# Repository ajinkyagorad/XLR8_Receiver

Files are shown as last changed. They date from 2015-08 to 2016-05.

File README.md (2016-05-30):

# XLR8_Receiver
XLR8 Receiver (IIT Bombay) design files

###For more info go to [Document](https://github.com/ajinkyagorad/XLR8_Receiver/tree/master/Document)
###The android mobile app is available [here](https://play.google.com/store/apps/details?id=com.udiboy.xlr8remotecontrol)

##Circuit Schematic
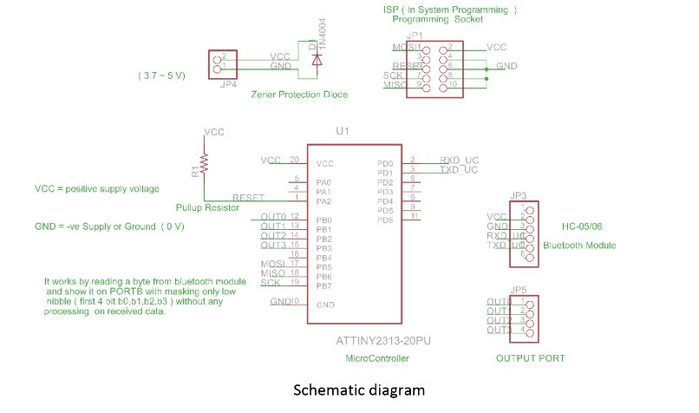
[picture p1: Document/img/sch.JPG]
Circuit Schematic

##Circuit PCB
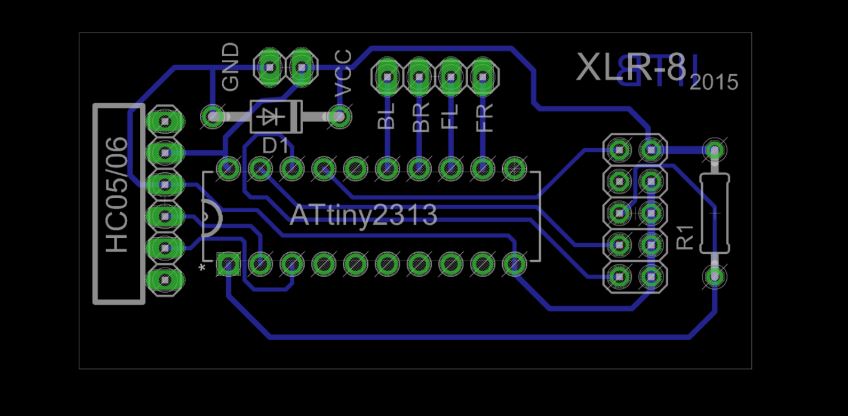
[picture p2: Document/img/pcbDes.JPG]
Circuit PCB

##Flowchart of Implementation (on uC)
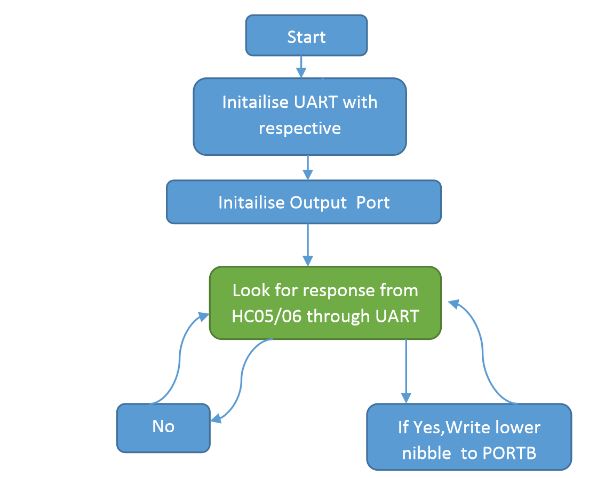
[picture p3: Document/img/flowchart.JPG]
flowchart


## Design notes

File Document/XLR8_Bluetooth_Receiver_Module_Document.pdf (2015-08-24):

XLR8 Bluetooth Receiver ModuleDocument

Electronics Club

IIT Bombay

This page is intentionally left blank

## About

This document describes the implementation of Bluetooth controlled port using Attiny2313A.

This document ( program ) is limited to 4 bit output , but can be easily changed upto 8 bits & beyond by configuring the data packet protocol ( user decided ).

## Index

## Contents

## Introduction

Bluetooth controlled port is the digital output access over Bluetooth ( in this case 4 bit access) and is achieved using a Bluetooth module (HC05/06) and a microcontroller ( ATtiny2313A).

This can be controlled through any Bluetooth device which can access the connection to the HC05/06.

## Software

Following software is used in making of the program & programming

- Atmel Studio 6.0 - alternative is WinAVR (windows), AVRgcc (Linux)
- Avrdude – alternative is Extreme Burner (GUI)
- EAGLE 7.0 (for CAD designing ) – alternative (free source : KiCAD )

## Hardware

Following hardware is used

- HC05/06 Bluetooth Module
- Attiny 2313A microcontroller
- USBASP programmer

## Schematic & PCB Diagram

Schematic & PCB designing is done in EAGLE7.2.0 Light Version

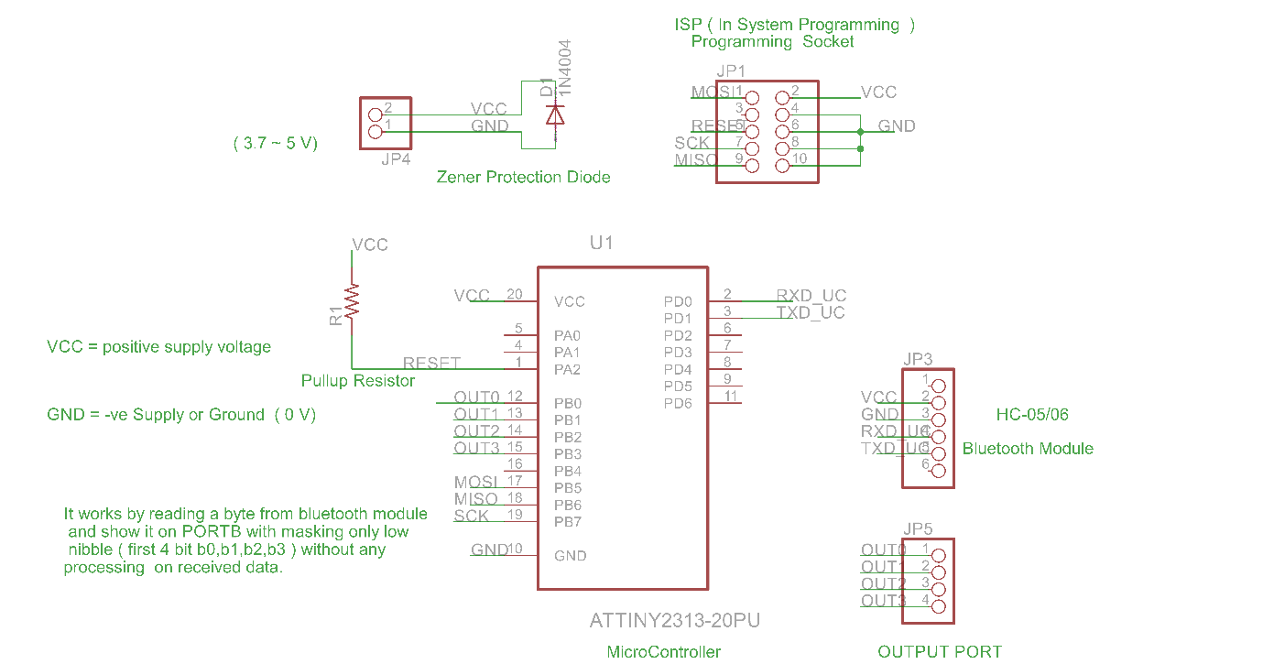
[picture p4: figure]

Schematic diagram

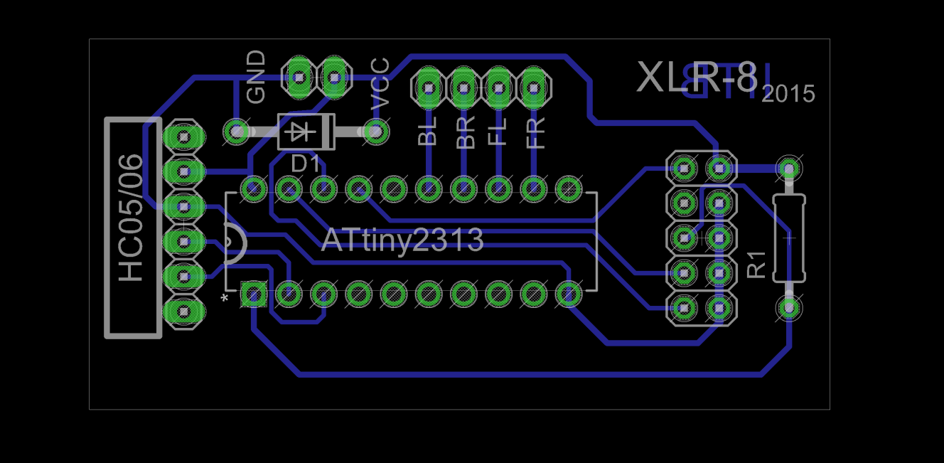
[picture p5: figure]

PCB top-bottom-silkscreen

Eagle files can be found at https://github.com/ajinkyagorad/XLR8_Receiver/tree/master/EAGLE_Files

## Software

Software ( program ) for ATtiny2313 is written in Atmel Studio 6.0

/*
* XLR8_module.c
*
* Created: 20-07-2015 10:07:35 PM
* Author: Ajinkya & Meet
*/
#include <avr/io.h> | // definations for registers

//default frequency of operation 1M
void USARTInit(unsigned int ubrr_value, uint8_t x2, uint8_t stopbits) { //from datasheet :
// Set baud rate
UBRRL = ubrr_value & 255;
UBRRH = ubrr_value >> 8;
// Frame Format: asynchronous, 8 data bits, no parity, 1/2 stop bits
UCSRC = _BV(UCSZ1) | _BV(UCSZ0);
if(stopbits == 2) UCSRC |= _BV(USBS);
if(x2) UCSRA = _BV(U2X); // 2x
// USART Data Register Empty Interrupt Enable UCSRB = _BV(UDRIE);
// Enable The receiver and transmitter
UCSRB |= _BV(RXEN) | _BV(TXEN);
}

int main() {

USARTInit(5, 0, 1); // initialise uart to baud rate 9600, no parity , 1 stopbit
DDRB=0xFF; | // make all pins on port B as output
PORTB = 0x00; | // initially make all pins low
while(1) | //endless loop
while( !(UCSRA & (1<<RXC)) ); | // wait for data to be received in
uart UDR register
char temp = UDR; | // copy data,
PORTB = UDR&(0X0F); | // write data directly
to port
}
}

For more information related to microcontroller refer http://www.atmel.com/images/doc2543.pdf

### Program Flowchart

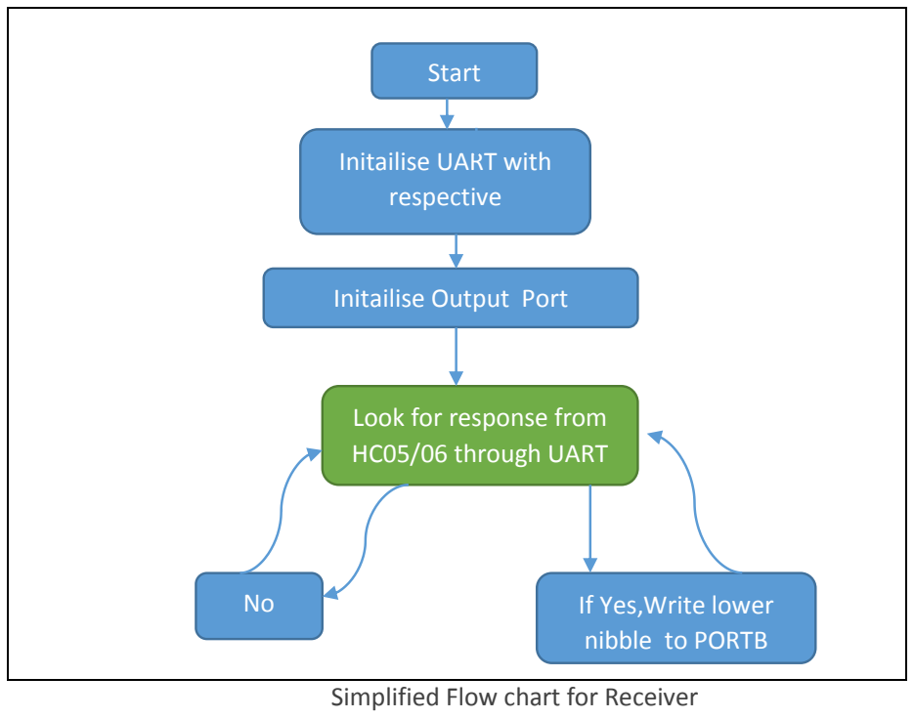
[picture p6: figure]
Simplified Flow chart for Receiver; Start; Initailise UART with respective; Initailise Output Port; Look for response from HC05/06 through UART; If Yes,Write lower nibble to PORTB

This program directly writes the data received through Bluetooth Module ( 1 byte ) to PORTB of the ATtiny 2313A.

The schematic diagram ( circuit diagram ) given is for low nibble ( 4 lower bits) of PORTB.

The default clock frequency of 1MHz (internal RC oscillator) is used as a clock source.

## Programming

Avrdude programming command using usbasp is

avrdude –c usbasp –p attiny2313 –U flash:w:XLR8_module.hex
For more details refer ‘XLR8_Bluetooth_Programming_Guide.pdf’ at https://github.com/ajinkyagorad/XLR8_Receiver/tree/master/Document

## PCB Soldering Tutorial

Refer ‘XLR8_Bluetooth_RF_module_Soldering_guide.pdf’ for picture guide at https://github.com/ajinkyagorad/XLR8_Receiver/tree/master/Document

## Future Work

- This can be improved for larger number of bit access by defining a Bluetooth UART packet protocol, or up to n bits by masking for first n bits ( n < 8 ) according to application.
- If possible to change the firmware on the BC417 chip on Bluetooth module for directly using HC05 pins remotely without the need for the external microcontroller (see http://byron76.blogspot.in/ ). Which can enable many functions like sampling voltage remotely without uC and at a low cost.

## Reference Links

- Github Project Link https://github.com/ajinkyagorad/XLR8_Receiver
- Eagle files https://github.com/ajinkyagorad/XLR8_Receiver/tree/master/EAGLE_Files
- Datasheet for ATtiny2313A http://www.atmel.com/images/doc2543.pdf
- Guides documents
https://github.com/ajinkyagorad/XLR8_Receiver/tree/master/Document
- Interesting future work http://byron76.blogspot.in/
- Eagle Download http://www.cadsoftusa.com/download-eagle/
- Extreme Burner http://extremeelectronics.co.in/avr-tutorials/gui-software-for-usbasp-based-usb-avr-programmers/ (http://extremeelectronics.co.in/avr-tutorials/gui-software-for-usbasp-based-usb-avr-programmers/)
- KiCAD http://www.kicad-pcb.org/display/KICAD/KiCad+EDA+Software+Suite
- Atmel Studio http://www.atmel.com/microsite/atmel_studio6/
- WinAVR http://winavr.sourceforge.net/

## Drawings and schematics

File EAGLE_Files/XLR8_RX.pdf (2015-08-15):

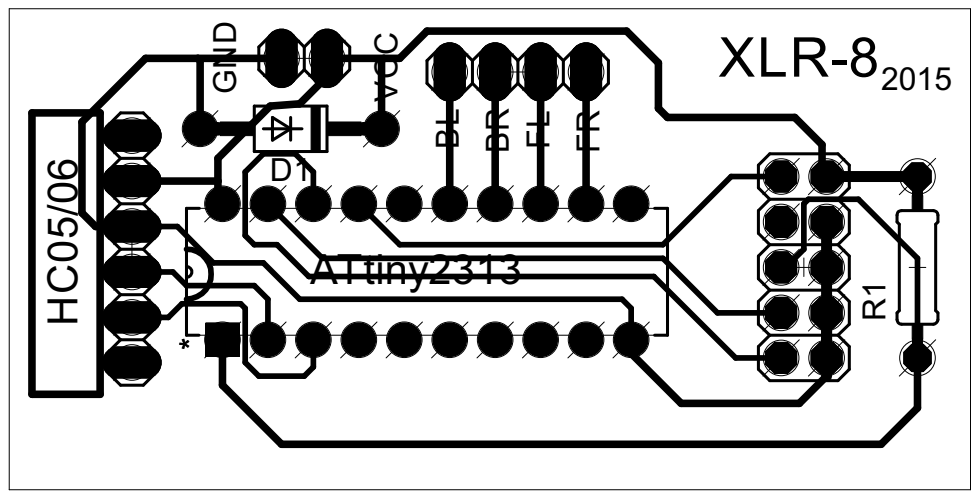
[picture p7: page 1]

VCC GND FRFL BRBL ATtiny2313 HC05/06 XLR-82015 * R1 D1

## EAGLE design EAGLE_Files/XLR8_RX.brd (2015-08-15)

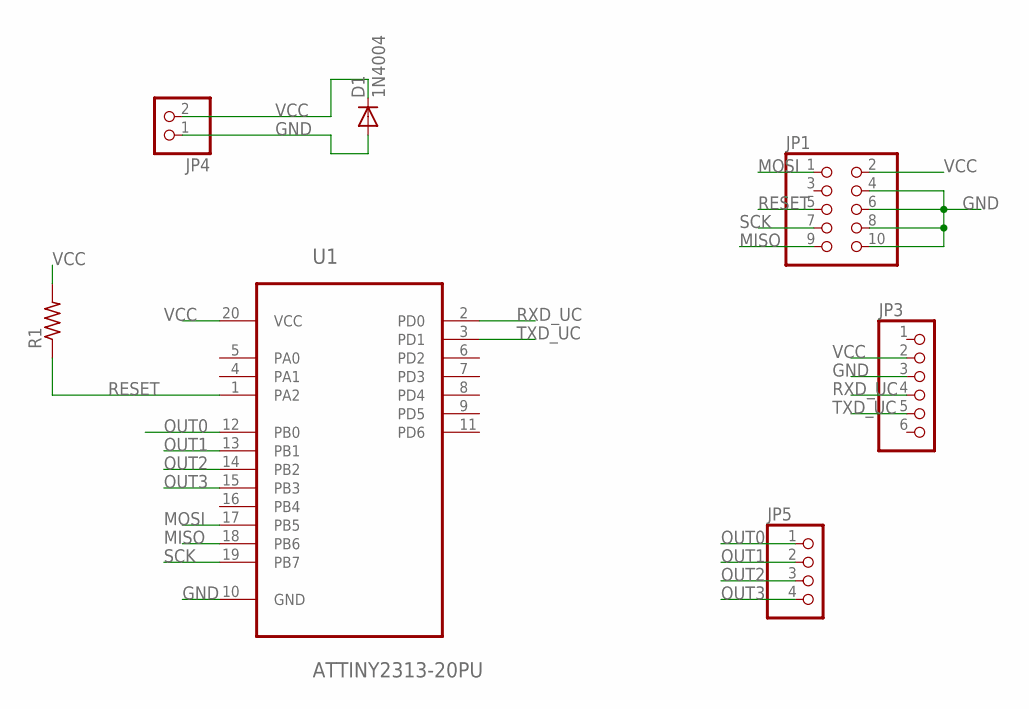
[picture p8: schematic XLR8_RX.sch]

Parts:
D1: 1N4004; DO41-10
JP1: PINHD-2X5; 2X05
JP3: PINHD-1X6; 1X06
JP4: PINHD-1X2; 1X02
JP5: PINHD-1X4; 1X04
R1: R-US_0207/10; 0207/10
U1: ATTINY2313-20PU; DIP254P762X533-20

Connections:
GND: D1.A, JP1.4, JP1.6, JP1.8, JP1.10, JP3.3, JP4.1, U1.10 (GND)
MISO: JP1.9, U1.18 (PB6)
MOSI: JP1.1, U1.17 (PB5)
OUT0: JP5.1, U1.12 (PB0)
OUT1: JP5.2, U1.13 (PB1)
OUT2: JP5.3, U1.14 (PB2)
OUT3: JP5.4, U1.15 (PB3)
RESET: JP1.5, R1.1, U1.1 (PA2)
RXD_UC: JP3.4, U1.2 (PD0)
SCK: JP1.7, U1.19 (PB7)
TXD_UC: JP3.5, U1.3 (PD1)
VCC: D1.C, JP1.2, JP3.2, JP4.2, R1.2, U1.20 (VCC)

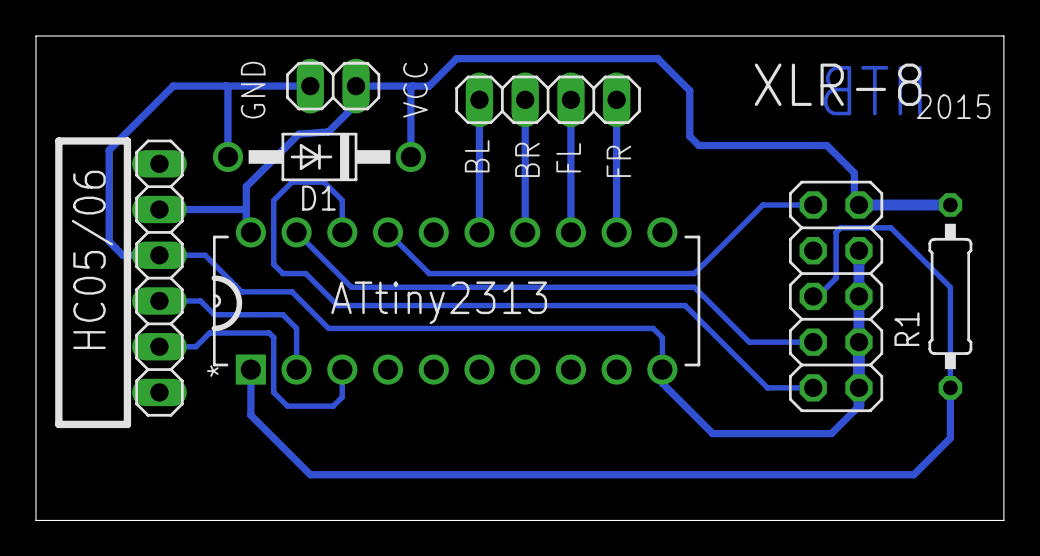
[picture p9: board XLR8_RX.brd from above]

Board: 2 copper layers, 53.8 x 26.9 mm, 7 parts (0 on the bottom side), 12 nets.

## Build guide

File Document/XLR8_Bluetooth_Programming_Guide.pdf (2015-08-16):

XLR8 Bluetooth Programming Guide

Electronics Club
IIT Bombay

About

This guide describes the programming of ATtiny 2313A on XLR8 Bluetooth receiver Module.

## Requirement

- Hardware
- USB ASP Programmer with slow clock option
- Software
- UsbASP
- Download the latest drivers for usbasp from http://www.fischl.de/usbasp/ or exactly (http://www.fischl.de/usbasp/usbasp.2011-05-28.tar.gz )
- Avrdude
- Windows : WinAVR (easy install of avrdude ) (http://sourceforge.net/projects/winavr/files/)
- Linux : directly install avrdude (http://ubuntuhandbook.org/index.php/2014/09/install-avrdude-6-1-ubuntu-1404/) (http://ubuntuhandbook.org/index.php/2014/09/install-avrdude-6-1-ubuntu-1404/)

▪
- Raw Program file ( HEX file ) [available at https://github.com/ajinkyagorad/XLR8_Receiver/blob/master/XLR8_module/Debug/XLR8_module.hex] (https://github.com/ajinkyagorad/XLR8_Receiver/blob/master/XLR8_module/Debug/XLR8_module.hex)
- Download by clicking on ‘Raw’ and Ctrl+S to desired location (desktop )

## Steps for software

- Install WinAVR (Windows)/ avrdude ( Linux )
- Install drivers for usbasp (windows)
- Windows 8+ refer (https://openchrysalis.wordpress.com/2014/09/26/installingusbasp-driver-software-in-windows-8-1/ (https://openchrysalis.wordpress.com/2014/09/26/installing-usbasp-driver-software-in-windows-8-1/) )

## Steps

- Connect programmer with PC & with the XLR8 module

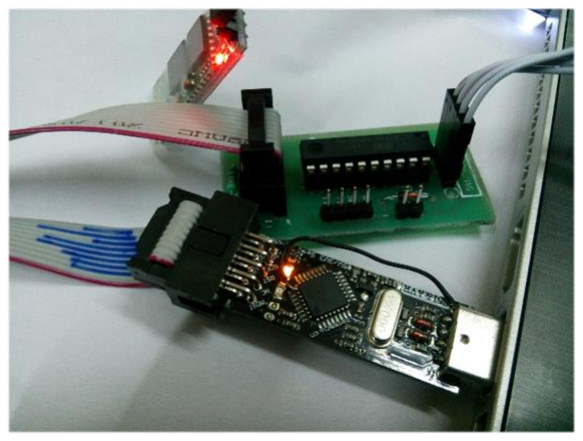
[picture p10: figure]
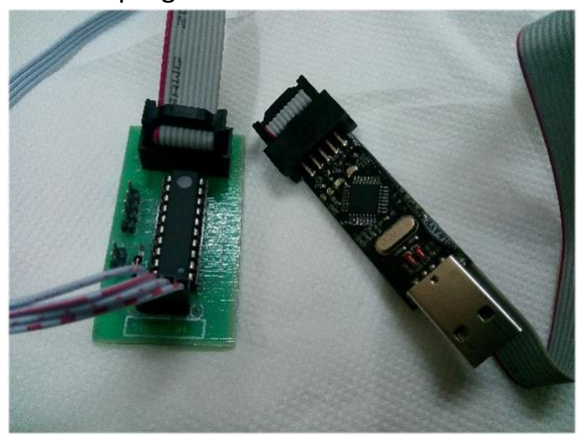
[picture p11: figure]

- Set programmer to slow clock ( if jumper available ) (otherwise follow debugging)
- Open terminal and cd to directory where hex file is downloaded
cd <directory_path>
eg : cd Desktop

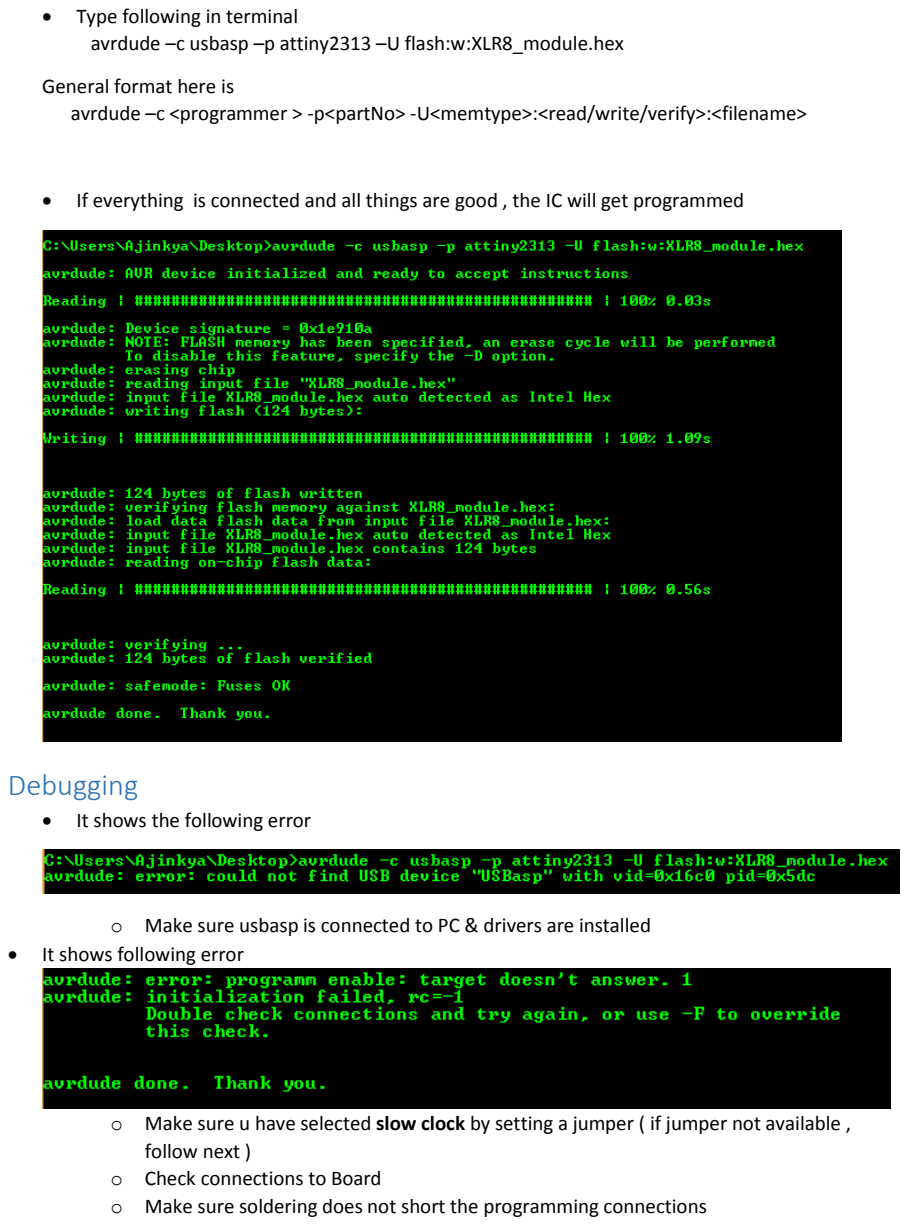
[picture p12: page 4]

- Type following in terminal
avrdude –c usbasp –p attiny2313 –U flash:w:XLR8_module.hex

General format here is
avrdude –c <programmer > -p<partNo> -U<memtype>:<read/write/verify>:<filename>
- If everything is connected and all things are good , the IC will get programmed

## Debugging

- It shows the following error
- Make sure usbasp is connected to PC & drivers are installed
- It shows following error
- Make sure u have selected slow clock by setting a jumper ( if jumper not available , follow next )
- Check connections to Board
- Make sure soldering does not short the programming connections

- Make connections by connecting PC2 pin of atmega8 on usbasp to ground
- ( u may look at http://txyzinfo.blogspot.in/2012/11/how-to-program-attiny2313-withusbasp.html (http://txyzinfo.blogspot.in/2012/11/how-to-program-attiny2313-with-usbasp.html) )

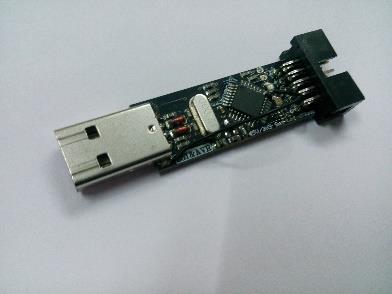
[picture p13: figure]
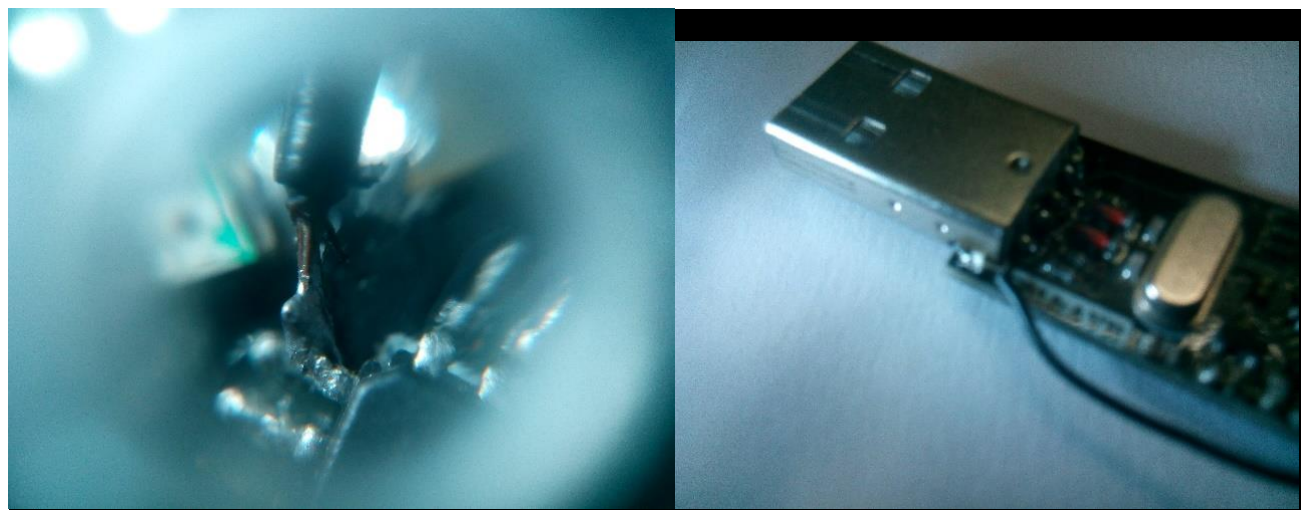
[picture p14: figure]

Closeup View of wire

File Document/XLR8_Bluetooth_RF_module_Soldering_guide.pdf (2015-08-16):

## XLR8 Blutooth RF module

### Soldering Guide

Electronics Club

IIT Bombay

## About

This guide describes the soldering of PCB ( Printed Circuit Board) for XLR8 RF Bluetooth module.

It presumes the following

- have the components for building the PCB.
- Have done soldering before.

## Components

Components required for building the Bluetooth RF module

- XLR8 PCB
- Attiny 2313A microcontroller
- 2x5 ISP male connector

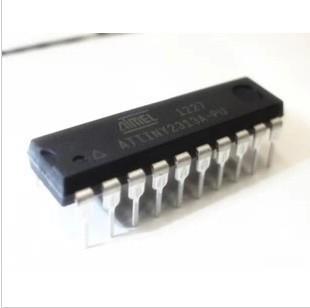
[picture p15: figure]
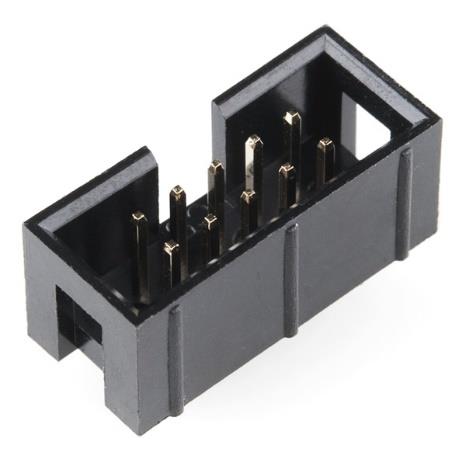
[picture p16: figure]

- 1x2 & two 1x4 male bergstrip ( can be right angled or straight)

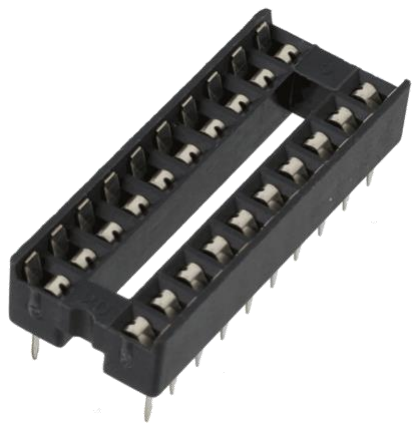
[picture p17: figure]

- 20 pin DIP IC Holder

- Zener Diode ( 5.1V )

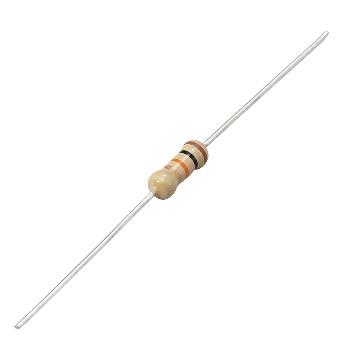
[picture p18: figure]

- Resistor in range 1K to 10 K

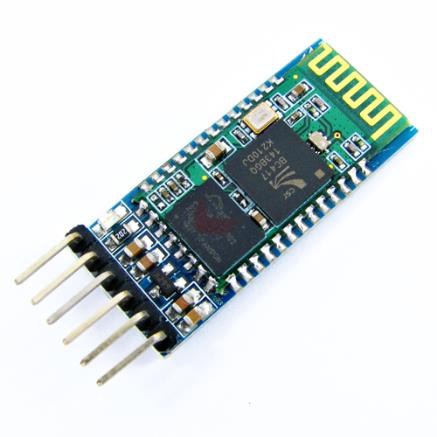
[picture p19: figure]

- Bluetooth Module HC05/06

## Some guidelines to follow

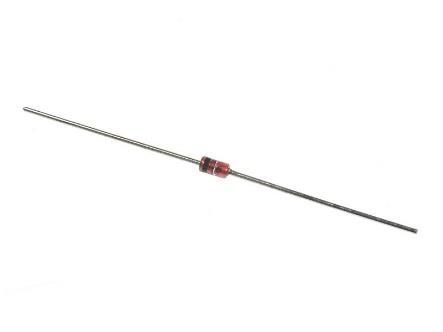
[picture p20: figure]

- Start soldering from the bigger sized flat components ( like IC holder , Right angled bergstrip, resistors… ) and then taller components ( like capacitors, Straight bergstrip, connectors).
- You may apply solder flux for good soldering finish.
- Do not apply too much solder as it is unnecessary.

## Steps

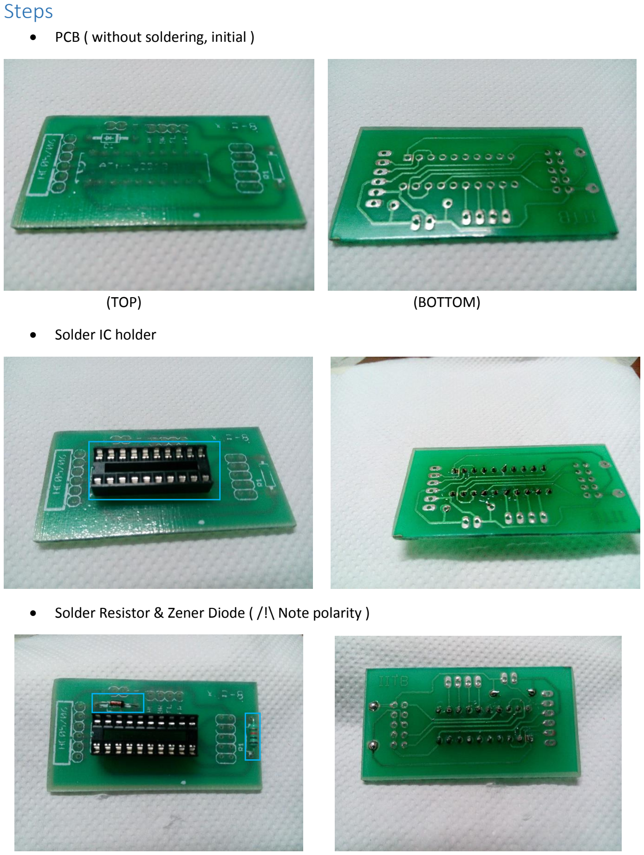
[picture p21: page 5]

- PCB ( without soldering, initial )
(TOP) | (BOTTOM)
- Solder IC holder
- Solder Resistor & Zener Diode ( /!\ Note polarity )

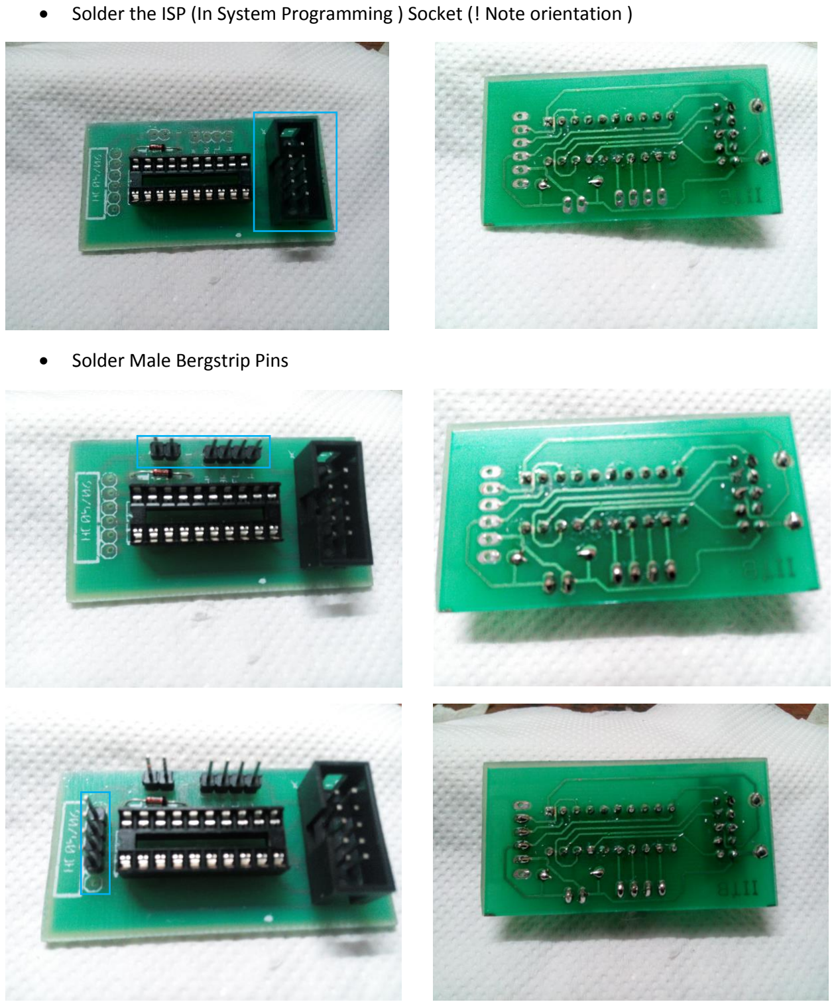
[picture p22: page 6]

- Solder the ISP (In System Programming ) Socket (! Note orientation )
- Solder Male Bergstrip Pins

## Final Assembly

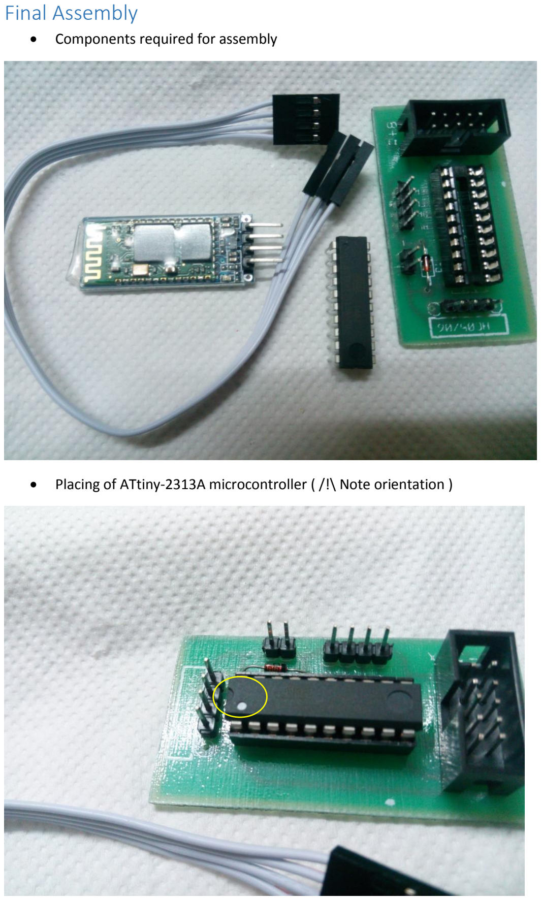
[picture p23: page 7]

- Components required for assembly
- Placing of ATtiny-2313A microcontroller ( /!\ Note orientation )

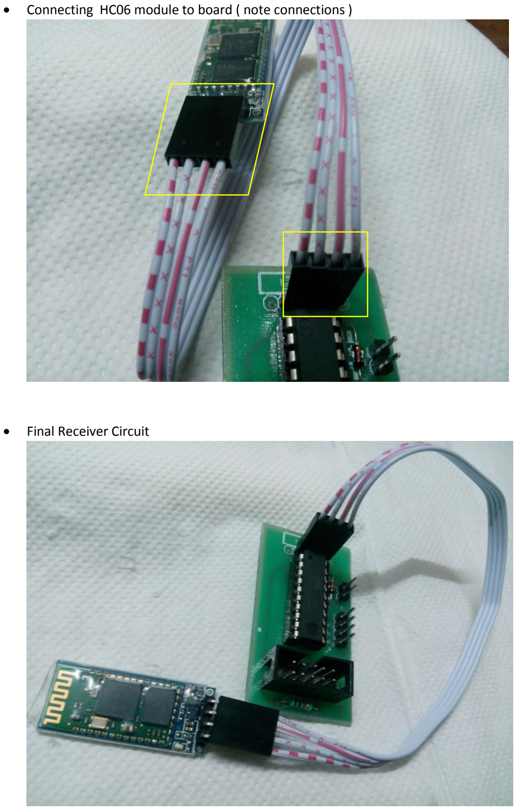
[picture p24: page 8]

- Connecting HC06 module to board ( note connections )
- Final Receiver Circuit

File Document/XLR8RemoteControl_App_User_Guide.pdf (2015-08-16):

XLR8RemoteControl App User Guide

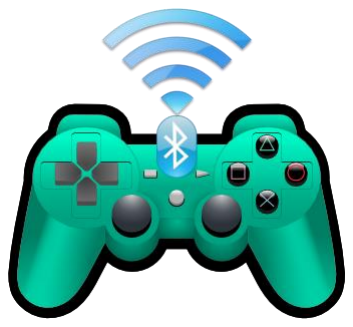
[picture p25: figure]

The App connects your phone to the bot via your phone’s Bluetooth.

Install the apk, and search for this above icon to open the app.
Check this link if you don’t know how to install apk files :
http://www.tech-recipes.com/rx/22616/androidallow-installation-of-non-market-apps/ (http://www.tech-recipes.com/rx/22616/android-allow-installation-of-non-market-apps/)

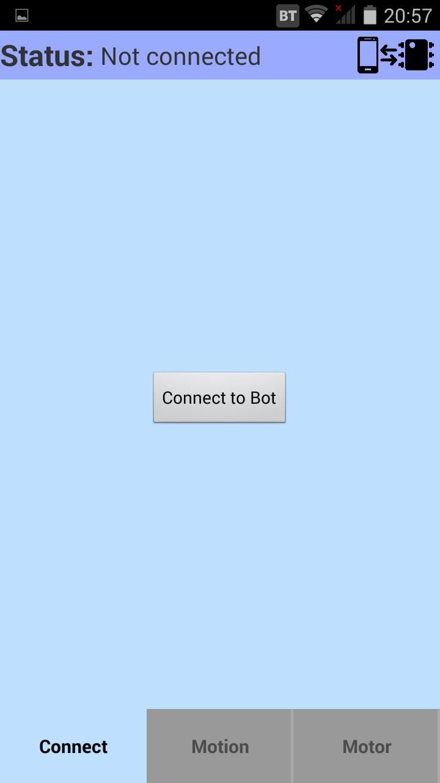
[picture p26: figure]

Connect to the bot first, either by clicking the button at centre of the page or the icon in top-right corner

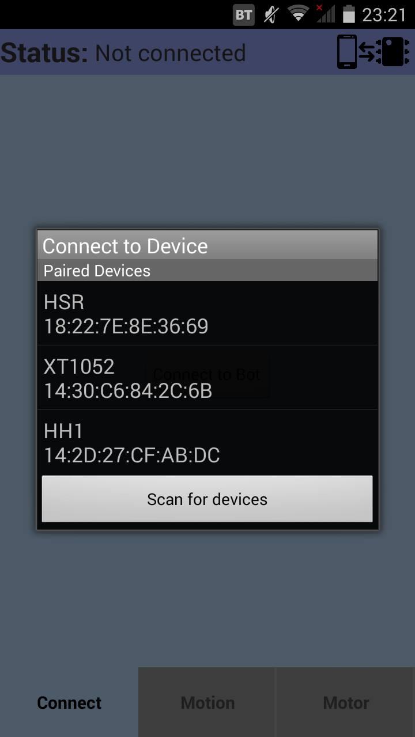
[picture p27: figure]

You will need to pair first. Click on “Scan for devices”

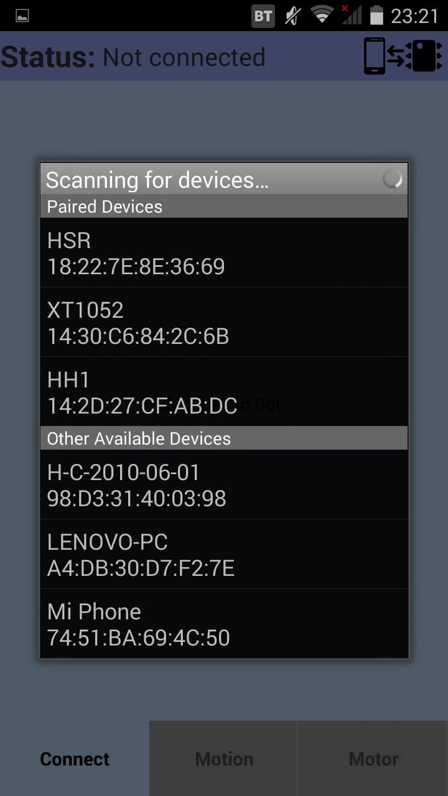
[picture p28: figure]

Select a device named “H-C-<random-string-ofnumbers>” from the list of Other Available Devices Note: If you see more than one “H-C…” devices, you might be in range of more than one bots. Go to an isolated area with your bot and then pair. If you connect with the wrong bot, it will be a problem

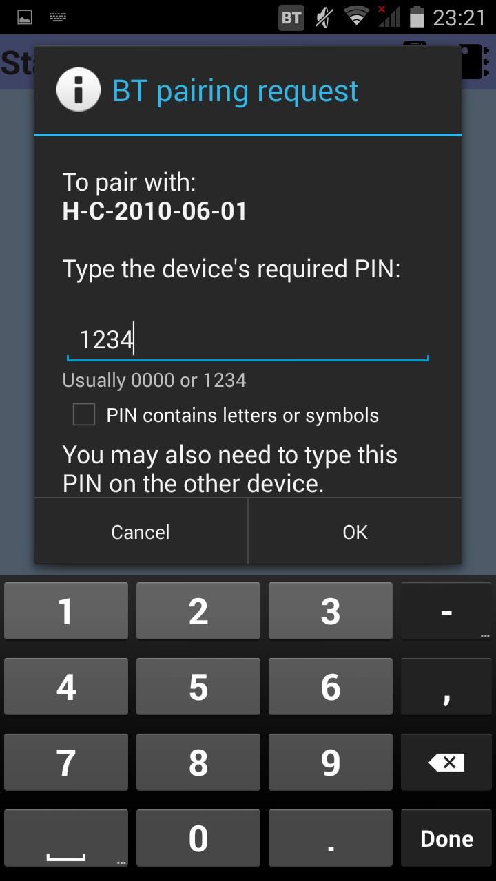
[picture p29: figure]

Enter PIN as “1234”. It is the default.

You have now paired successfully,

“Connect to bot”
again to start rolling!

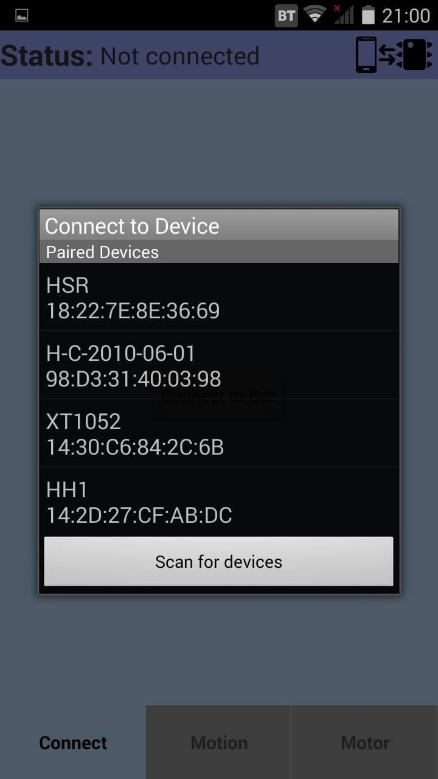
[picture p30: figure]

Choose the device with which you paired earlier. It will appear in the list of Paired Devices and name will be same “H-C…”

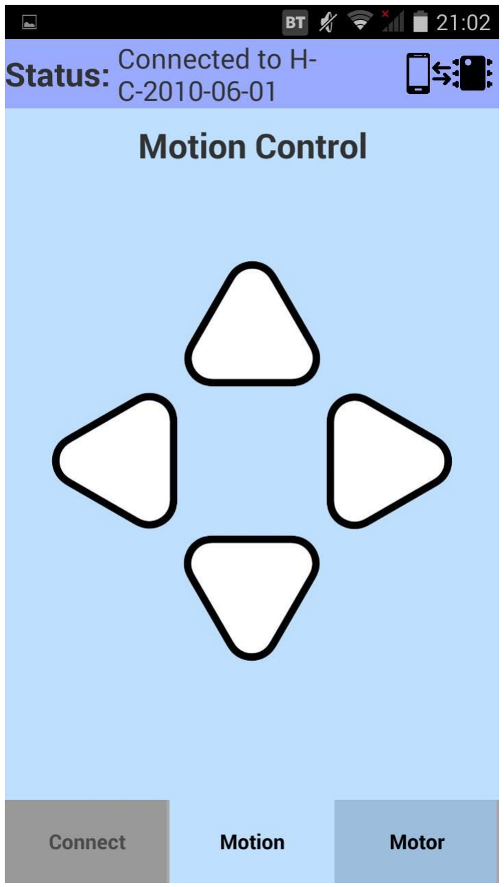
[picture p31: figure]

This is “Motion Control” mode. It is a basic mode with which you can move your bot forward, backward and turn it left and right with the respective buttons. Note: This will only work with differential mechanism

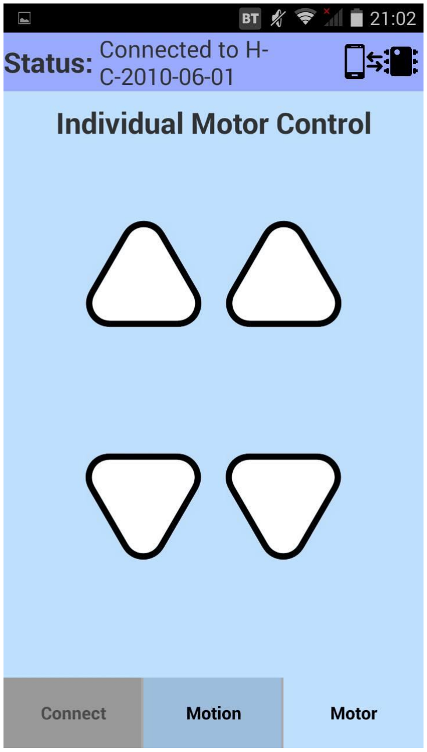
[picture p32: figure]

This is “Individual Motor Control” mode. You can control left and right motors individually by pressing the buttons simultaneously. Each motor can be moved forward or backward.
